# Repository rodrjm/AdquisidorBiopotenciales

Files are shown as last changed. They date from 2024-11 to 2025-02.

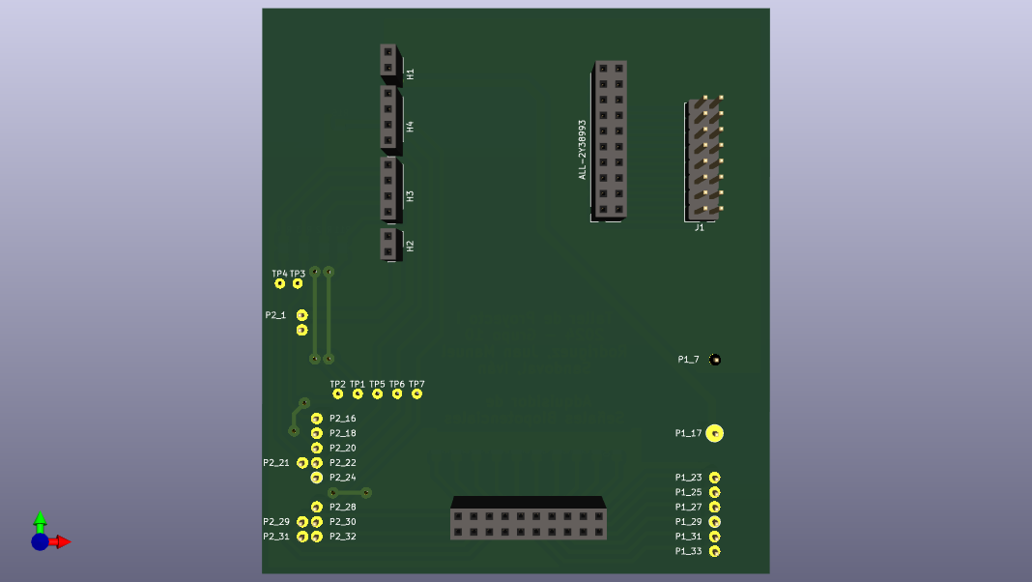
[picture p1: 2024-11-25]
Hardware/KiCad/AdquisidorSeñalesBiopotenciales_3d_front.png

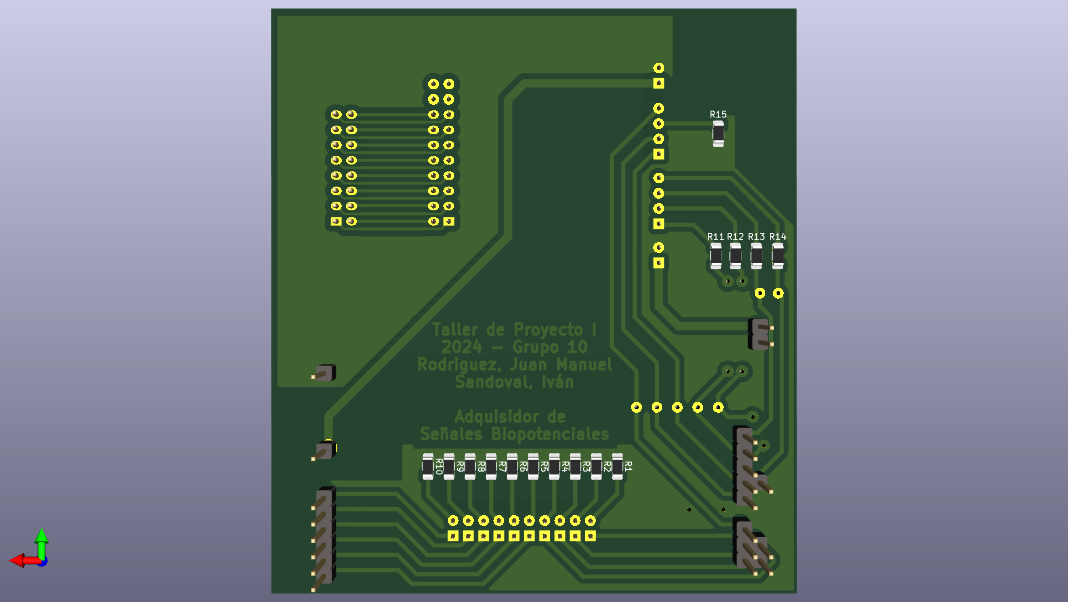
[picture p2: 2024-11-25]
Hardware/KiCad/AdquisidorSeñalesBiopotenciales_3d_back.PNG

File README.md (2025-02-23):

# Adquisidor de Biopotenciales con ADS131E08

Este proyecto consiste en un sistema de adquisición de biopotenciales utilizando el convertidor analógico a digital (ADC) ADS131E08 de Texas Instruments. El sistema permite adquirir y visualizar señales de biopotenciales en tiempo real a través de una interfaz gráfica en Python.

## Descripción

El proyecto se compone de dos partes principales:

1.  **Firmware (C):**
    * Implementado en C para la placa EDU-CIAA-NXP.
    * Configura y controla el ADS131E08 a través de comunicación SPI.
    * Adquiere datos de biopotenciales y los envía a través de comunicación UART.
    * Proporciona una interfaz de usuario básica para controlar la adquisición y configuración del ADC.
2.  **Software (Python):**
    * Implementado en Python utilizando las bibliotecas `serial`, `numpy` y `pyqtgraph`.
    * Recibe los datos de biopotenciales a través del puerto serial.
    * Procesa y visualiza los datos en tiempo real en una interfaz gráfica.

## Estructura de archivos

* `adquisidorBiopotenciales.c`: Contiene la función principal y la inicialización del hardware.
* `adquisidorBiopotenciales.h`: Declaraciones para `adquisidorBiopotenciales.c`.
* `ADS131E08.c`: Implementación de las funciones para controlar el ADS131E08.
* `ADS131E08.h`: Declaraciones para `ADS131E08.c`.
* `funcionamiento.c`: Lógica principal del sistema (menú, adquisición de datos, etc.).
* `funcionamiento.h`: Declaraciones para `funcionamiento.c`.
* `GPIO.c`: Implementación de las funciones para controlar los GPIO.
* `GPIO.h`: Declaraciones para `GPIO.c`.
* `SPI.c`: Implementación de las funciones para controlar la comunicación SPI.
* `SPI.h`: Declaraciones para `SPI.c`.
* `UART.c`: Implementación de las funciones para controlar la comunicación UART.
* `UART.h`: Declaraciones para `UART.c`.
* `adquisidorDatos.py`: Script de Python para recibir y visualizar los datos.

## Requisitos

* **Hardware:**
    * Placa EDU-CIAA-NXP.
    * ADS131E08.
    * Display de 10 LEDs (opcional).
* **Software:**
    * CIAA-Launcher (disponible en: [https://github.com/epernia/software/releases/tag/r1.1.0](https://github.com/epernia/software/releases/tag/r1.1.0)).
    * Python 3.x.
    * Bibliotecas de Python: `serial`, `numpy`, `pyqtgraph`, `PyQt6`.

## Instalación

1.  **Firmware:**
    * Compila el código C utilizando el Embedded IDE de CIAA-Launcher, o otro IDE de su preferencia.
    * Carga el firmware en la placa EDU-CIAA-NXP.
2.  **Software:**
    * Instala las bibliotecas de Python necesarias:

    \`\`\`bash
    pip install pyserial numpy pyqtgraph PyQt6
    \`\`\`

## Uso

1.  Conecta el ADS131E08 a la placa EDU-CIAA-NXP y los sensores de biopotenciales a las entradas del ADC.
2.  Conecta la placa EDU-CIAA-NXP a tu computadora a través de un puerto serial.
3.  Ejecuta el script de Python `adquisidorDatos.py`.
4.  Utiliza la interfaz de usuario en la placa EDU-CIAA-NXP para controlar la adquisición y configuración del ADC.
5.  Visualiza las señales de biopotenciales en la interfaz gráfica.

## Mejoras

* Implementar un modo de USB más rápido para aprovechar la potencia del sensor.
* Implementar un filtrado digital de las señales.
* Agregar más opciones de configuración a través de la interfaz de usuario.
* Mejorar la interfaz gráfica con más funcionalidades.
* Agregar manejo de errores del ADC.
* Modularizar el código C para mejor mantenibilidad.
* Agregar documentación detallada del código.

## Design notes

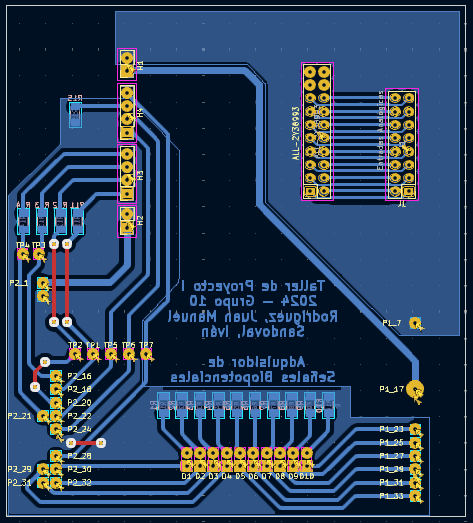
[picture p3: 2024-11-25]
Hardware/KiCad/AdquisidorSeñalesBiopotenciales_pcb.PNG

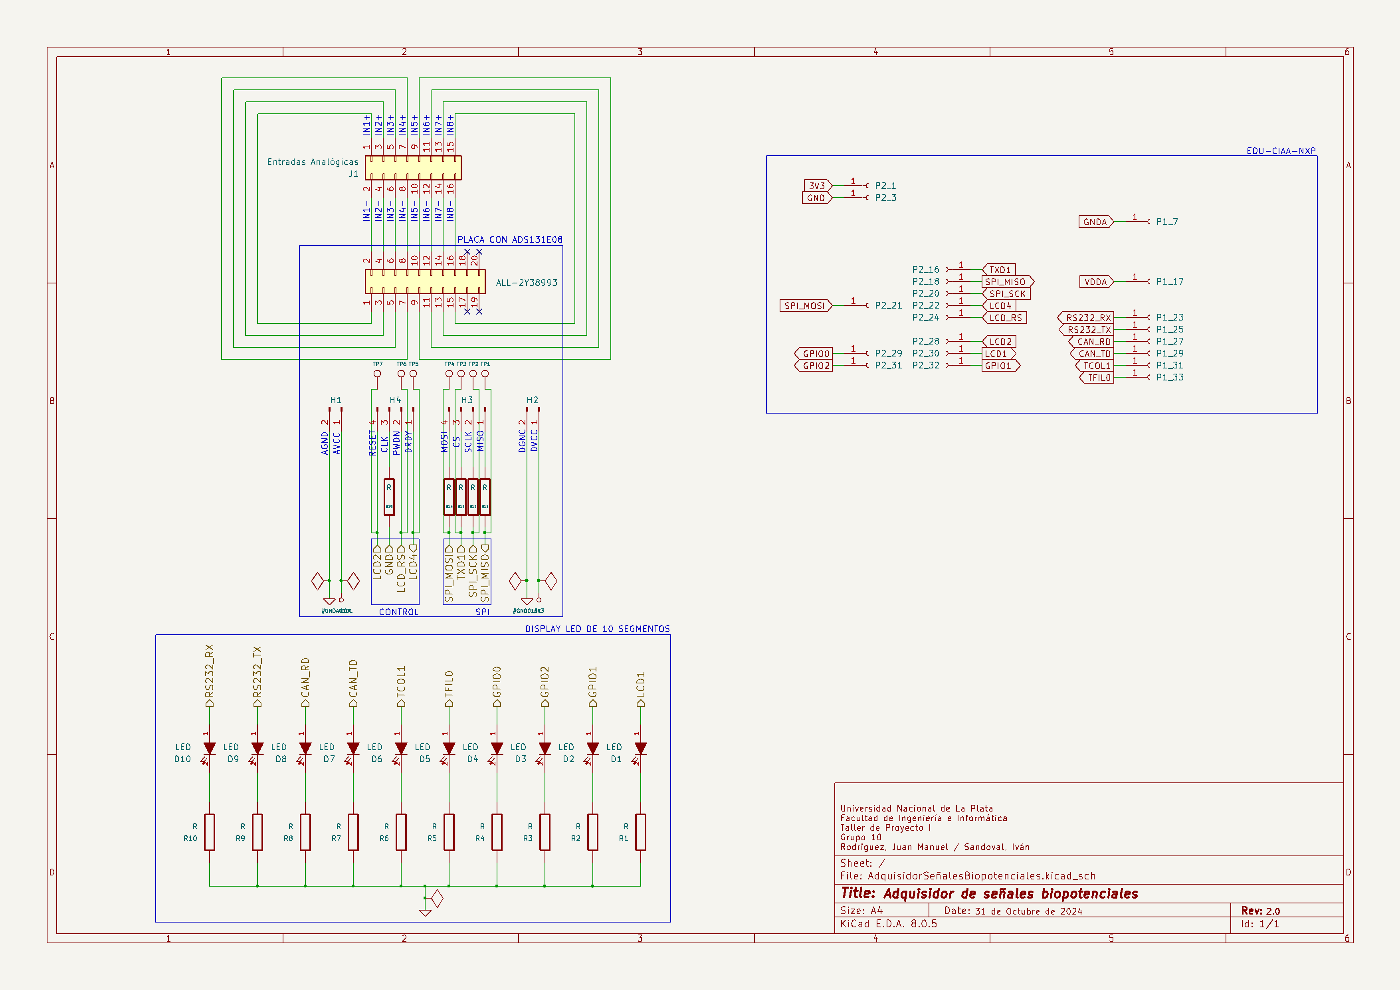
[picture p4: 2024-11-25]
Hardware/KiCad/AdquisidorSeñalesBiopotenciales_sch.png

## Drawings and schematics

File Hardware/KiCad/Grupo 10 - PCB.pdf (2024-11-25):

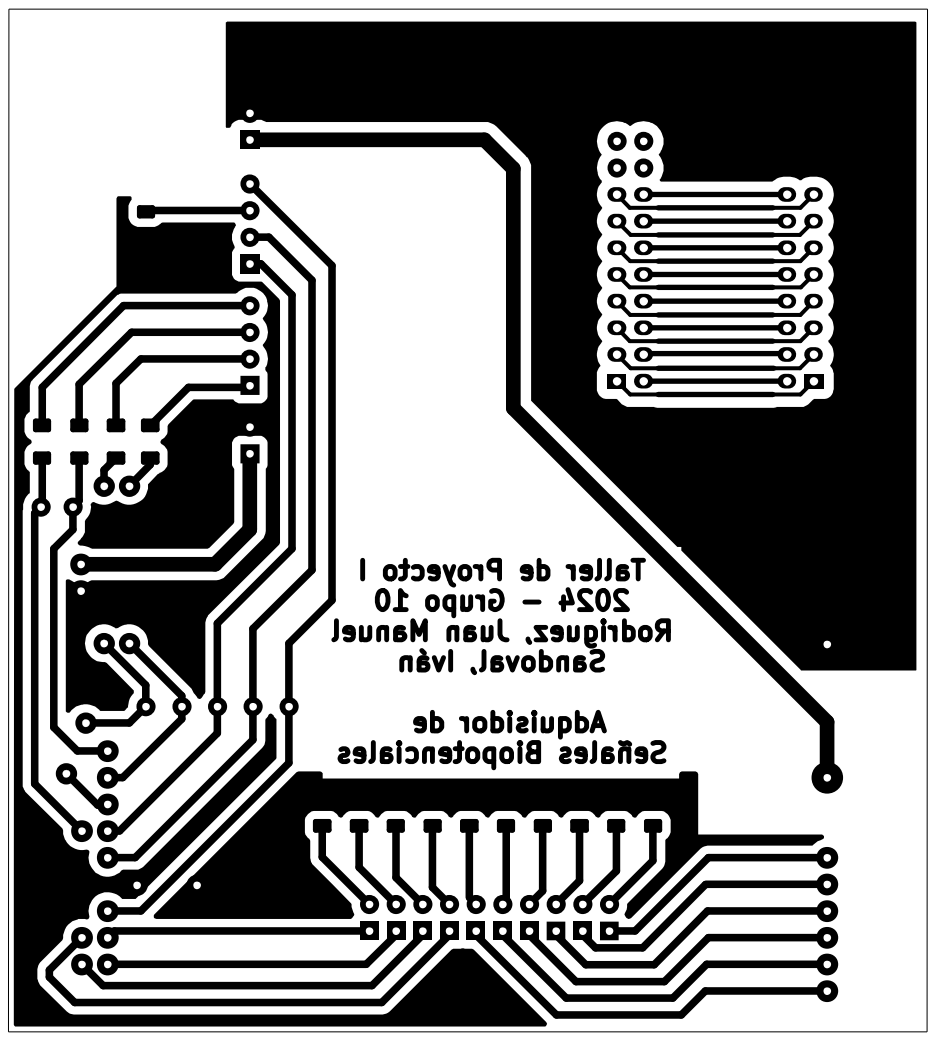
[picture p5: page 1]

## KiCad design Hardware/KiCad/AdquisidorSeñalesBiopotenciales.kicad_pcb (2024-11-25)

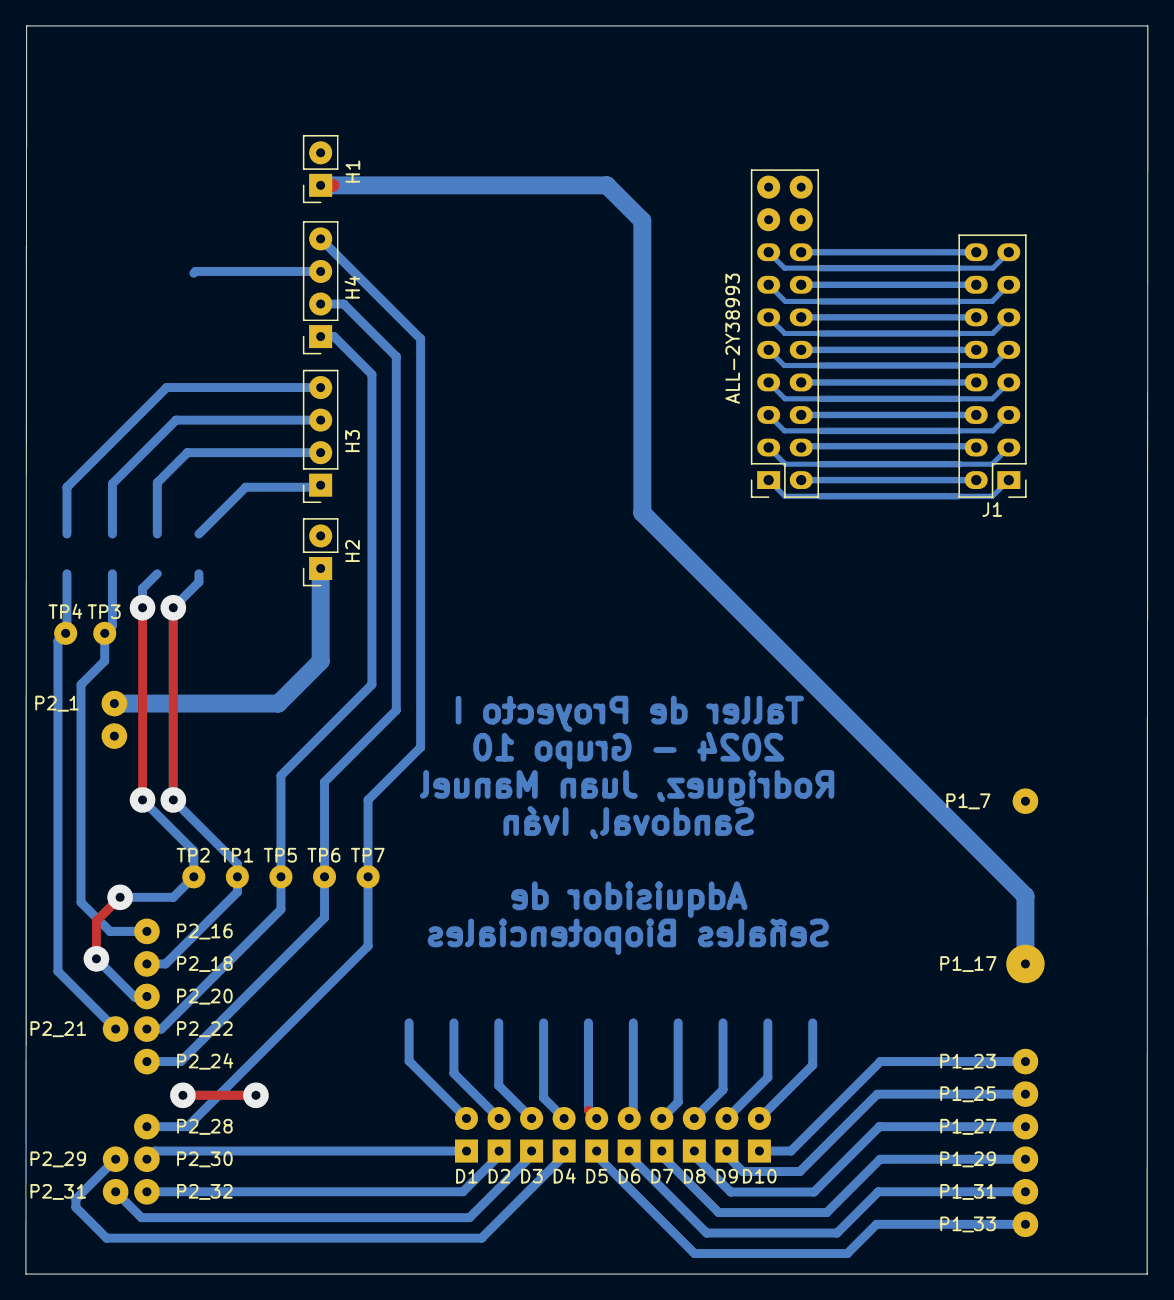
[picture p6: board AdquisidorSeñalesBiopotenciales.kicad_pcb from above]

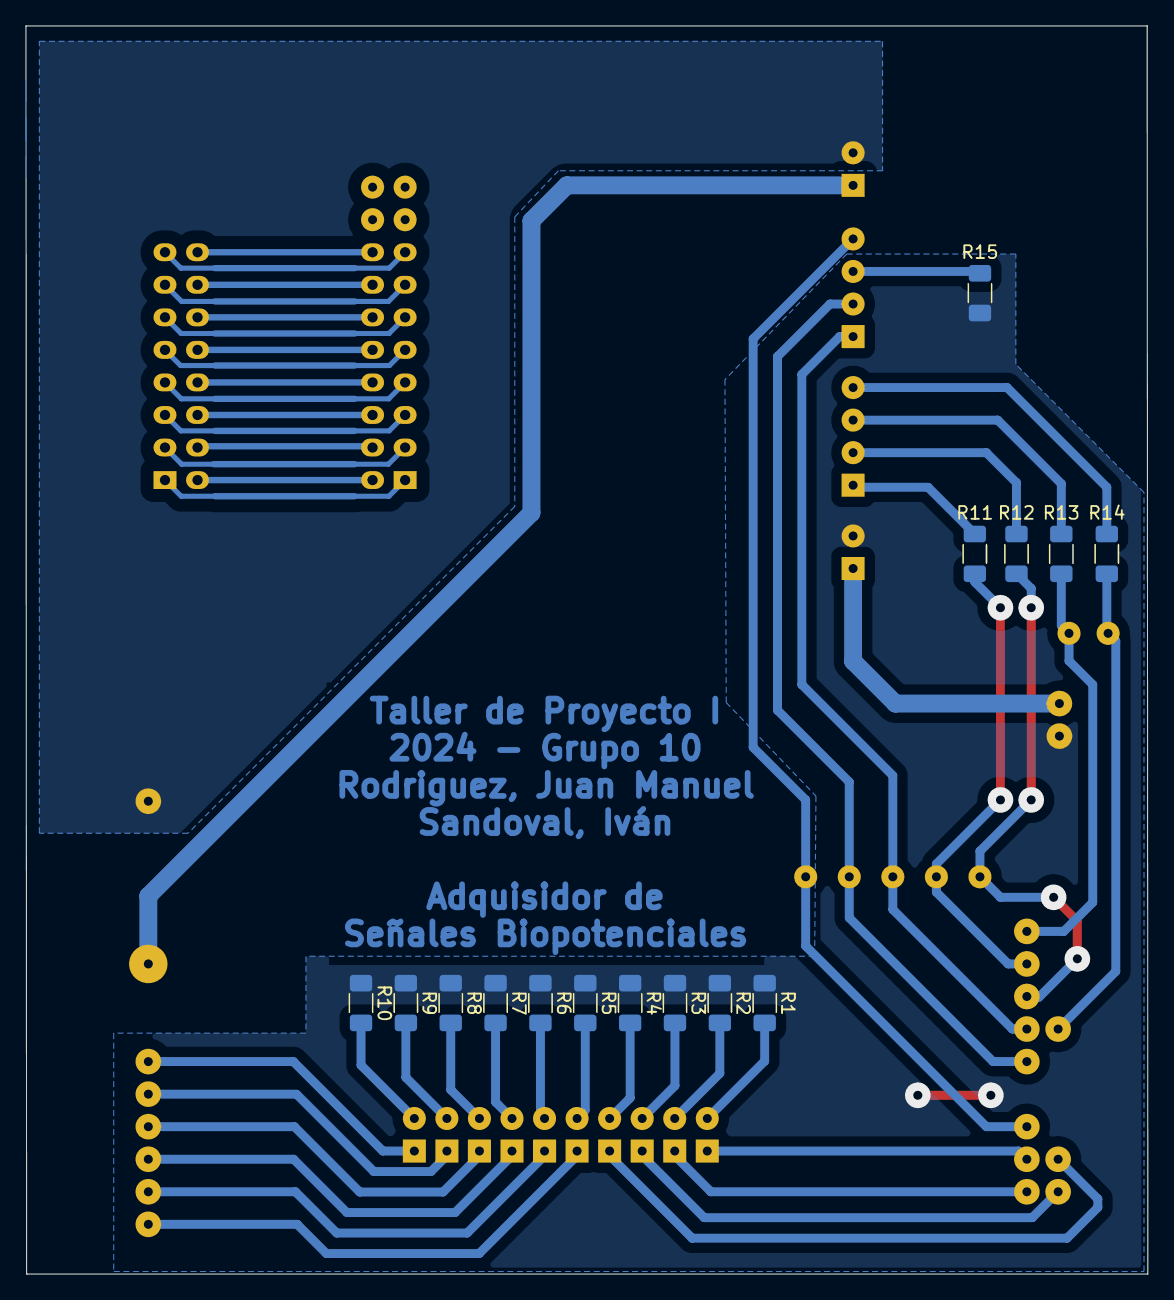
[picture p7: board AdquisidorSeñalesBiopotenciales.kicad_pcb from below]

Board: 2 copper layers, 87.6 x 97.4 mm, 59 parts (36 on the bottom side), 52 nets.

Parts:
ALL-2Y38993: Conn_02x10_Odd_Even; PinSocket_2x10_P2.54mm_Vertical
D1, D2, D3, D4, D5, D6, D7, D8, D9, D10: LED; PinSocket_2x01_P2.54mm_Vertical
H1, H2: Conn_01x02_Pin; PinSocket_1x02_P2.54mm_Vertical
H3, H4: Conn_01x04_Pin; PinSocket_1x04_P2.54mm_Vertical
J1: Entradas Analógicas; PinHeader_2x08_P2.54mm_Vertical
P1_7, P1_17, P1_23, P1_25, P1_27, P1_29, P1_31, P1_33, P2_1, P2_3, P2_16, P2_18, P2_20, P2_21, P2_22, P2_24, P2_28, P2_29, P2_30, P2_31, P2_32: Conn_01x01_Socket; PinHeader_1x01_P2.54mm_Vertical
R1, R2, R3, R4, R5, R6, R7, R8, R9, R10, R11, R12, R13, R14, R15: R; R_1206_3216Metric_Pad1.30x1.75mm_HandSolder
TP1, TP2, TP3, TP4, TP5, TP6, TP7: TestPoint; TestPoint_THTPad_1.5x1.5mm_Drill0.7mm

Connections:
3V3: H2.1, P2_1.1
CAN_RD: D8.1 (A), P1_27.27
CAN_TD: D7.1 (A), P1_29.29
GND: H2.2, P2_3.3, R1.1, R2.1, R3.1, R4.1, R5.1, R6.1, R7.1, R8.1, R9.1, R10.1, R15.1
GNDA: H1.2, P1_7.7
GPIO0: D4.1 (A), P2_29.29
GPIO1: D2.1 (A), P2_32.32
GPIO2: D3.1 (A), P2_31.31
LCD1: D1.1 (A), P2_30.30
LCD2: H4.4, P2_28.28, TP7.1
LCD4: H4.1, P2_22.22, TP5.1
LCD_RS: H4.2, P2_24.24, TP6.1
unnamed: ALL-2Y38993.1, J1.1
unnamed: ALL-2Y38993.2, J1.2
unnamed: ALL-2Y38993.3, J1.3
unnamed: ALL-2Y38993.4, J1.4
unnamed: ALL-2Y38993.5, J1.5
unnamed: ALL-2Y38993.6, J1.6
unnamed: ALL-2Y38993.7, J1.7
unnamed: ALL-2Y38993.8, J1.8
unnamed: ALL-2Y38993.9, J1.9
unnamed: ALL-2Y38993.10, J1.10
unnamed: ALL-2Y38993.11, J1.11
unnamed: ALL-2Y38993.12, J1.12
unnamed: ALL-2Y38993.13, J1.13
unnamed: ALL-2Y38993.14, J1.14
unnamed: ALL-2Y38993.15, J1.15
unnamed: ALL-2Y38993.16, J1.16
unnamed: D1.2 (K), R1.2
unnamed: D2.2 (K), R2.2
unnamed: D3.2 (K), R3.2
unnamed: D4.2 (K), R4.2
unnamed: D5.2 (K), R5.2
unnamed: D6.2 (K), R6.2
unnamed: D7.2 (K), R7.2
unnamed: D8.2 (K), R8.2
unnamed: D9.2 (K), R9.2
unnamed: D10.2 (K), R10.2
unnamed: H3.1, R11.2
unnamed: H3.2, R12.2
unnamed: H3.3, R13.2
unnamed: H3.4, R14.2
unnamed: H4.3, R15.2
RS232_RX: D10.1 (A), P1_23.23
RS232_TX: D9.1 (A), P1_25.25
SPI_MISO: P2_18.18, R11.1, TP1.1
SPI_MOSI: P2_21.21, R14.1, TP4.1
SPI_SCK: P2_20.20, R12.1, TP2.1
TCOL1: D6.1 (A), P1_31.31
TFIL0: D5.1 (A), P1_33.33
TXD1: P2_16.16, R13.1, TP3.1
VDDA: H1.1, P1_17.17

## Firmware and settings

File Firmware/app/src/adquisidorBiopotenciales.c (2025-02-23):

/*
 * adquisidorBiopotenciales.c
 */


#include "adquisidorBiopotenciales.h" // Incluye el encabezado del archivo "adquisidorBiopotenciales.h".
#include "board.h" // Incluye el encabezado para la inicialización de la placa.
#include "UART.h" // Incluye el encabezado para la comunicación UART.
#include "ADS131E08.h" // Incluye el encabezado para el manejo del ADS131E08.
#include "funcionamiento.h" // Incluye el encabezado para la lógica de funcionamiento del sistema.
#include "SPI.h" // Incluye el encabezado para la comunicación SPI.


/*
 * @brief Función de inicialización del hardware.
 */
static void InitHardware(void); // Declara la función estática InitHardware.


/**
 * @brief Inicializa el hardware necesario para el sistema.
 */
static void InitHardware(void)
{
   Board_Init(); // Inicializa la placa (configura pines, periféricos, etc.).
   SystemCoreClockUpdate(); // Actualiza la variable SystemCoreClock con la frecuencia del reloj del sistema.
   SysTick_Config(SystemCoreClock / 1000); // Configura el SysTick para generar interrupciones cada 1 milisegundo.
   GPIO_Init(); // Inicializa los GPIO (configura pines como entradas o salidas).
   SPI_Init(); // Inicializa el periférico SPI.
   SPI_Setup(); // Configura los parámetros de la comunicación SPI (velocidad, modo, etc.).
   UART_Init(); // Inicializa el periférico UART para la comunicación serial.
}


/**
 * @brief Función principal del programa.
 * @return Retorna 0 al finalizar la ejecución (aunque este programa no termina).
 */
int main(void)
{
   InitHardware(); // Llama a la función para inicializar el hardware.
   delayMs(500); // Espera 500 milisegundos para permitir que el hardware se estabilice.
   Board_LED_Toggle(1); // Invierte el estado del LED 1 (enciende si está apagado, apaga si está encendido).
   delayMs(500); // Espera 500 milisegundos.
   Board_LED_Toggle(1); // Invierte nuevamente el estado del LED 1.

   Funcionamiento_Init(); // Inicializa la lógica de funcionamiento del sistema.
   while (1) // Bucle infinito para la ejecución continua del programa.
   {
      Funcionamiento_Menu(); // Llama a la función principal de la lógica de funcionamiento.
   }
}

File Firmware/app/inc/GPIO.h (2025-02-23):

#ifndef GPIO_H_
#define GPIO_H_


#include "lpc_types.h" // Incluye el archivo de encabezado lpc_types.h, que define tipos de datos estándar para microcontroladores LPC.
#include "board.h"     // Incluye el archivo de encabezado board.h, que define constantes y funciones relacionadas con la placa.


/**
 * @defgroup Libreria GPIO
 * @ingroup "Adquisidor de señales biopotenciales"
 * Driver para controlar los puertos GPIO.
 */


/**
 * Definiciones y declaraciones.
 */
#define GPIO_PORT0 0 // Definición del número de puerto GPIO0.
#define GPIO_PORT1 1 // Definición del número de puerto GPIO1.
#define GPIO_PORT2 2 // Definición del número de puerto GPIO2.
#define GPIO_PORT3 3 // Definición del número de puerto GPIO3.

#define LED1_PORT 2  // Definición del puerto del LED1.
#define LED1_PIN  4  // Definición del pin del LED1.
#define LED2_PORT 3  // Definición del puerto del LED2.
#define LED2_PIN  3  // Definición del pin del LED2.
#define LED3_PORT 3  // Definición del puerto del LED3.
#define LED3_PIN  4  // Definición del pin del LED3.
#define LED4_PORT 3  // Definición del puerto del LED4.
#define LED4_PIN  0  // Definición del pin del LED4.
#define LED5_PORT 2  // Definición del puerto del LED5.
#define LED5_PIN  0  // Definición del pin del LED5.
#define LED6_PORT 3  // Definición del puerto del LED6.
#define LED6_PIN  12 // Definición del pin del LED6.
#define LED7_PORT 5  // Definición del puerto del LED7.
#define LED7_PIN  9  // Definición del pin del LED7.
#define LED8_PORT 5  // Definición del puerto del LED8.
#define LED8_PIN  8  // Definición del pin del LED8.
#define LED9_PORT 5  // Definición del puerto del LED9.
#define LED9_PIN  3  // Definición del pin del LED9.
#define LED10_PORT 5 // Definición del puerto del LED10.
#define LED10_PIN 4  // Definición del pin del LED10.


/**
 * @brief Inicializar puerto GPIO.
 *
 * Prototipo de la función GPIO_Init(), que inicializa el puerto GPIO.
 */
void GPIO_Init();


/**
 * @brief Desinicialización del puerto GPIO.
 *
 * Prototipo de la función GPIO_deInit(), que desinicializa el puerto GPIO.
 */
void GPIO_deInit();


/**
 * @brief Establece el estado de un pin GPIO.
 *
 * Prototipo de la función GPIO_setPinState(), que establece el estado de un pin GPIO.
 *
 * @param port Número del puerto GPIO.
 * @param pin Número del pin GPIO.
 * @param state TRUE para establecerlo en alto, FALSE para establecerlo en bajo.
 */
void GPIO_setPinState(uint8_t port, uint8_t pin, bool state);


/**
 * @brief Obtener el estado de un pin GPIO.
 *
 * Prototipo de la función GPIO_getPinState(), que obtiene el estado de un pin GPIO.
 *
 * @param port Número del puerto GPIO.
 * @param pin Número del pin GPIO.
 * @return TRUE si el pin está en alto, FALSE si está en bajo.
 */
bool GPIO_getPinState(uint8_t port, uint8_t pin);


/**
 * @brief Establece la dirección de un pin GPIO.
 *
 * Prototipo de la función GPIO_setPinDir(), que establece la dirección de un pin GPIO.
 *
 * @param port Número del puerto GPIO.
 * @param pin Número del pin GPIO.
 * @param output TRUE para salida, FALSE para entrada.
 */
void GPIO_setPinDir(uint8_t port, uint8_t pin, bool output);


/**
 * @brief Obtener la dirección de un pin GPIO.
 *
 * Prototipo de la función GPIO_getPinDir(), que obtiene la dirección de un pin GPIO.
 *
 * @param port Número del puerto GPIO.
 * @param pin Número del pin GPIO.
 * @return TRUE si está configurado como salida, FALSE si está configurado como entrada.
 */
bool GPIO_getPinDir(uint8_t port, uint8_t pin);


/**
 * @brief Alterna un pin GPIO al estado opuesto.
 *
 * Prototipo de la función GPIO_setPinToggle(), que alterna el estado de un pin GPIO.
 *
 * @param port Número del puerto GPIO.
 * @param pin Número del pin GPIO.
 */
void GPIO_setPinToggle(uint8_t port, uint8_t pin);


/**
 * @brief Establece el estado de un LED.
 *
 * Prototipo de la función setLed(), que establece el estado de un LED.
 *
 * @param port Número del puerto GPIO del LED.
 * @param pin Número del pin GPIO del LED.
 * @param state TRUE para apagar el LED, FALSE para encender el LED.
 */
void setLed(uint8_t port, uint8_t pin, bool state);


/**
 * @brief Apaga todos los LEDs.
 *
 * Prototipo de la función GPIO_displayOFF(), que apaga todos los LEDs.
 */
void GPIO_displayOFF();


/**
 * @brief Enciende todos los LEDs.
 *
 * Prototipo de la función GPIO_displayON(), que enciende todos los LEDs.
 */
void GPIO_displayON();


/**
 * @brief Muestra el canal actual a través de LEDs.
 *
 * Prototipo de la función GPIO_displayCurrentChannel(), que muestra el canal actual a través de LEDs.
 *
 * @param currentChannel Número del canal actual.
 */
void GPIO_displayCurrentChannel(uint8_t currentChannel);
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

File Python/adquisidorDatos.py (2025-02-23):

import struct  # Módulo para trabajar con datos binarios empaquetados.
import serial  # Módulo para comunicación serial (puerto COM).
import time  # Módulo para funciones relacionadas con el tiempo.
import numpy as np  # Módulo para computación numérica (manejo de arrays).
import pyqtgraph as pg  # Módulo para graficación interactiva.
from PyQt6.QtCore import QTimer  # Clase para crear temporizadores en PyQt.

# Configuración del puerto serial
ser = serial.Serial("COM4", 588000)  # Crea un objeto Serial para el puerto COM4 a 588000 baudios.
ser.timeout = 0.001  # Establece un tiempo de espera de 1 milisegundo para la lectura serial.
ser.rtscts = True  # Habilita el control de flujo RTS/CTS.

# Configuración de PyQtGraph
app = pg.mkQApp()  # Crea una aplicación PyQtGraph.
win = pg.GraphicsLayoutWidget()  # Crea una ventana gráfica.
plot = win.addPlot()  # Agrega un gráfico a la ventana.
plot.setYRange(-2.5, 2.5)  # Establece el rango del eje Y del gráfico.
win.resize(800, 600)  # Establece el tamaño de la ventana.
win.show()  # Muestra la ventana.

# Crear la curva
curve = plot.plot(pen="b")  # Crea una curva en el gráfico con color azul.

# Inicialización de variables
muestras = 1000  # Número de muestras a mostrar en el gráfico.
Fs = 1000  # Frecuencia de muestreo (muestras por segundo).
T = 1 / Fs  # Período de muestreo (tiempo entre muestras).
t = np.arange(muestras) * T  # Vector de tiempo para el eje X del gráfico.
ECG = np.zeros(muestras)  # Array para almacenar los datos del ECG.
LSB = (2 * 2.4) / (2**24)  # Valor del bit menos significativo (LSB) para convertir datos digitales a voltaje.
data_buffer = [] # Buffer para almacenar datos recibidos del puerto serial

# Función para procesar los datos recibidos del puerto serial
def procesar_datos(data):
    if len(data) == 3:  # Verifica si se recibieron 3 bytes de datos.
        # Extraer el bit más significativo (MSB)
        msb = (data[2] >> 7) & 1  # Obtiene el MSB del tercer byte.

        # Convertir los bytes a un entero
        valor_ecg = int.from_bytes(data, byteorder="little")  # Convierte los 3 bytes a un entero.

        # Aplicar la máscara antes de modificar el bit más significativo
        valor_ecg &= 0x007FFFFF  # Aplica una máscara para mantener solo los 23 bits menos significativos.

        # Establecer el bit más significativo si es necesario
        if msb == 1:  # Si el MSB es 1 (valor negativo):
            valor_ecg = -valor_ecg  # Convierte el valor a negativo.

        return valor_ecg  # Retorna el valor del ECG procesado.
    else:
        print("Tamaño de datos incorrecto")  # Imprime un mensaje de error si no se reciben 3 bytes.
        return None  # Retorna None en caso de error.

# Función para actualizar la gráfica con los nuevos datos
def update():
    global curve, ECG, data  # Indica que se utilizarán las variables globales.
    try:
        # Verificar si llega un nuevo byte que indique el comienzo de un nuevo dato
        data = ser.read(1)  # Lee un byte del puerto serial.
        if data == b"\xaa":  # Verifica si el byte leído es el byte de inicio (0xAA).
            # Leer 3 bytes de datos
            data = ser.read(3)  # Lee 3 bytes de datos del puerto serial.
            valor_ecg = procesar_datos(data)  # Procesa los datos recibidos.
            data_buffer.append(valor_ecg) # Agrega los datos al buffer

            if len(data_buffer) >= 50: # Si hay 50 o mas datos en el buffer
                # Convertir a voltaje
                ECG[-1] = valor_ecg * LSB  # Convierte el valor del ECG a voltaje y lo almacena en el array ECG.
                # Desplazar los datos hacia la izquierda
                ECG = np.roll(ECG, -1)  # Desplaza los datos del ECG una posición hacia la izquierda.
                # Actualizar la gráfica
                curve.setData(t, ECG)  # Actualiza la curva del gráfico con los nuevos datos.

                # Actualizar los datos de la curva y el rango del eje y
                plot.setYRange(min(ECG) - 0.01, max(ECG) + 0.01, padding=0)  # Ajusta el rango del eje Y del gráfico.

                plot.setXRange(t[-100], t[-1], padding=0)  # Muestra los últimos 100 puntos en el eje X.

                data_buffer.clear() # Limpia el buffer de datos

                app.processEvents()  # Permite que la interfaz gráfica se actualice.

    except serial.SerialException:  # Captura excepciones de comunicación serial.
        print("Error de comunicación serial")  # Imprime un mensaje de error.

# Timer para actualizar la gráfica
timer = QTimer()  # Crea un objeto QTimer.
timer.timeout.connect(update)  # Conecta la función update al evento de timeout del timer.
timer.start(1)  # Inicia el timer para que genere timeouts cada 1 milisegundo.

# Mantener la ventana abierta hasta que se cierre manualmente
if __name__ == "__main__":
    import sys  # Módulo para acceder a parámetros y funciones específicas del sistema.
    sys.exit(app.exec())  # Inicia el bucle de eventos de la aplicación PyQtGraph.

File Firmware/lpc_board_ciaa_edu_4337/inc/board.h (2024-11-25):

/*
 * @brief NGX Xplorer 4330 board file
 *
 * @note
 * Copyright(C) NXP Semiconductors, 2013
 * All rights reserved.
 *
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
 * @par
 * Permission to use, copy, modify, and distribute this software and its
 * documentation is hereby granted, under NXP Semiconductors' and its
 * licensor's relevant copyrights in the software, without fee, provided that it
 * is used in conjunction with NXP Semiconductors microcontrollers.  This
 * copyright, permission, and disclaimer notice must appear in all copies of
 * this code.
 */

#ifndef __BOARD_H_
#define __BOARD_H_

#include "chip.h"
/* board_api.h is included at the bottom of this file after DEBUG setup */

#ifdef __cplusplus
extern "C" {
#endif

/** @defgroup BOARD_NGX_XPLORER_4330 LPC4330 NGX Xplorer board support software API functions
 * @ingroup LPCOPEN_43XX_BOARD_NGX4330
 * The board support software API functions provide some simple abstracted
 * functions used across multiple LPCOpen board examples. See @ref BOARD_COMMON_API
 * for the functions defined by this board support layer.<br>
 * @{
 */

/** @defgroup BOARD_NGX_XPLORER_4330_OPTIONS BOARD: LPC4330 NGX Xplorer board options
 * This board has options that configure its operation at build-time.<br>
 * @{
 */

/** Define DEBUG_ENABLE to enable IO via the DEBUGSTR, DEBUGOUT, and
    DEBUGIN macros. If not defined, DEBUG* functions will be optimized
   out of the code at build time.
 */
#define DEBUG_ENABLE

/** Define DEBUG_SEMIHOSTING along with DEBUG_ENABLE to enable IO support
    via semihosting. You may need to use a C library that supports
   semihosting with this option.
 */
//#define DEBUG_SEMIHOSTING

/** Board UART used for debug output and input using the DEBUG* macros. This
    is also the port used for Board_UARTPutChar, Board_UARTGetChar, and
   Board_UARTPutSTR functions. */
#define DEBUG_UART LPC_USART2

/**
 * @}
 */

/* Board name */
#define BOARD_CIAA_EDU_NXP_4337

/* Build for RMII interface */
#define USE_RMII
#define BOARD_ENET_PHY_ADDR    0x00

#define LED_3 2
#define LED_2 1
#define LED_1 0
#define LED_RED 3
#define LED_GREEN 4
#define LED_BLUE 5

#define BOARD_TEC_1                 0
#define BOARD_TEC_2                 1
#define BOARD_TEC_3                 2
#define BOARD_TEC_4                 3

/**
 * @brief  Sets up board specific I2C interface
 * @param  id  : I2C Peripheral ID (I2C0, I2C1)
 * @return Nothing
 */
void Board_I2C_Init(I2C_ID_T id);

/**
 * @brief  Sets up I2C Fast Plus mode
 * @param  id  : Must always be I2C0
 * @return Nothing
 * @note   This function must be called before calling
 *          Chip_I2C_SetClockRate() to set clock rates above
 *          normal range 100KHz to 400KHz. Only I2C0 supports
 *          this mode.
 */
STATIC INLINE void Board_I2C_EnableFastPlus(I2C_ID_T id)
{
   Chip_SCU_I2C0PinConfig(I2C0_FAST_MODE_PLUS);
}

/**
 * @brief  Disable I2C Fast Plus mode and enables default mode
 * @param  id  : Must always be I2C0
 * @return Nothing
 * @sa     Board_I2C_EnableFastPlus()
 */
STATIC INLINE void Board_I2C_DisableFastPlus(I2C_ID_T id)
{
   Chip_SCU_I2C0PinConfig(I2C0_STANDARD_FAST_MODE);
}

/**
 * @brief  Initializes board specific GPIO Interrupt
 * @return Nothing
 */
void Board_GPIO_Int_Init(void);

/**
 * @brief  Initialize pin muxing for SSP interface
 * @param  pSSP    : Pointer to SSP interface to initialize
 * @return Nothing
 */
void Board_SSP_Init(LPC_SSP_T *pSSP);

bool Board_TEC_GetStatus(uint8_t button);

/**
 * @brief  Returns the MAC address assigned to this board
 * @param  mcaddr : Pointer to 6-byte character array to populate with MAC address
 * @return Nothing
 */
void Board_ENET_GetMacADDR(uint8_t *mcaddr);

/**
 * @brief  Initialize pin muxing for a UART
 * @param  pUART   : Pointer to UART register block for UART pins to init
 * @return Nothing
 */
void Board_UART_Init(LPC_USART_T *pUART);

/**
 * @brief  Initialize pin muxing for SDMMC interface
 * @return Nothing
 */
void Board_SDMMC_Init(void);

/**
 * @brief  Initialize DAC
 * @param  pDAC    : Pointer to DAC register interface used on this board
 * @return Nothing
 */
void Board_DAC_Init(LPC_DAC_T *pDAC);

/**
 * @brief  Initialize ADC
 * @return Nothing
 */
STATIC INLINE void Board_ADC_Init(void){}

/**
 * @}
 */

#include "board_api.h"

#ifdef __cplusplus
}
#endif

#endif /* __BOARD_H_ */

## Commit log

2024-11-25 Commit inicial
    Commit inicial
    [ciaa-nxp.cfg]
2024-11-25 Modificacion velocidad UART y configuracion para muestreo 1kSPS
2024-11-25 Hojas de datos y archivos de KiCad
    [AdquisidorSeñalesBiopotenciales.kicad_pcb, AdquisidorSeñalesBiopotenciales.kicad_sch]
2024-11-25 Correccion archivos KiCad
    [AdquisidorSeñalesBiopotenciales.kicad_pcb]
2024-11-27 separacion de funciones
    Se separo la función de test y la de lectura de datos
2024-11-27 archivo de matlab
    Se agrego el archivo de matlab
2024-11-28 Agregacion de funcionamiento de leds y teclas
2024-11-28 modificacion Matlab
    se modifico el archivo de Matlab
2024-11-29 Correccion ecuacion del archivo de Matlab y ajustes en el funcionamiento del display
2024-11-29 Modificaciones varias
    Correccion del efecto rebote de los pulsadores
    Correccion del funcionamiento de los pulsadores y los leds
    Modificacion del funcionamiento general del sistema
    Modificacion del archivo de muestra en matlab
2024-12-02 modificación lectura de datos
    Se modifico la función de lectura de datos, y la del funcionamiento en general. Además se modifico la secuencia de encendido de los LEDs.
2024-12-02 Arreglos menores
    Eliminación de archivos que sobraban
2024-12-05 modificación matlab
    Se modifico el código de Matlab para poder visualizar la señal en el tiempo .
2024-12-09 Agregación de selección de modo para las señales
    Y actualización en el código de Matlab, intentando de que la gráfica se muestre más rápida
2024-12-11 Actualizacion de gitignore y adicion de byte de arranque
2024-12-11 Primera version del adquisidor de datos en Python
2024-12-11 Actualización del archivo de Python para que tome bien los valores negativos
2024-12-11 Arreglos en el funcionamiento del display de LEDs
    [GPIO.c, GPIO.h, funcionamiento.c]
2024-12-16 Correccion de muestra de datos
2024-12-19 señal Cuadrada y Triangular de prueba
    Se agregaron dos funciones, una para generar una señal cuadrada de -3mv a 3mv, y la otra para generar una señal triangular.
2025-02-23 Ajustes finales
    Actualización de comentarios generales del código y README.md
